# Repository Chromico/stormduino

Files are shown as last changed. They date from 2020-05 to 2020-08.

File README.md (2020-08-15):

# Stormduino Rev 2.2
An open source arduino uno clone designed in KiCad in collaboration with tecknologg and cyberstorm.mu .The board uses the CH340C as the USB to serial converter and an Atmega328p (DIP) as the microcontroller. The board design and schematic is open source so do whatever you wish with it :)

My website: https://tecknologg.website

Blog post: https://tecknologg.website/2020/02/02/stormduino-the-arduino-compatible-board-made-in-kicad/

# Front 

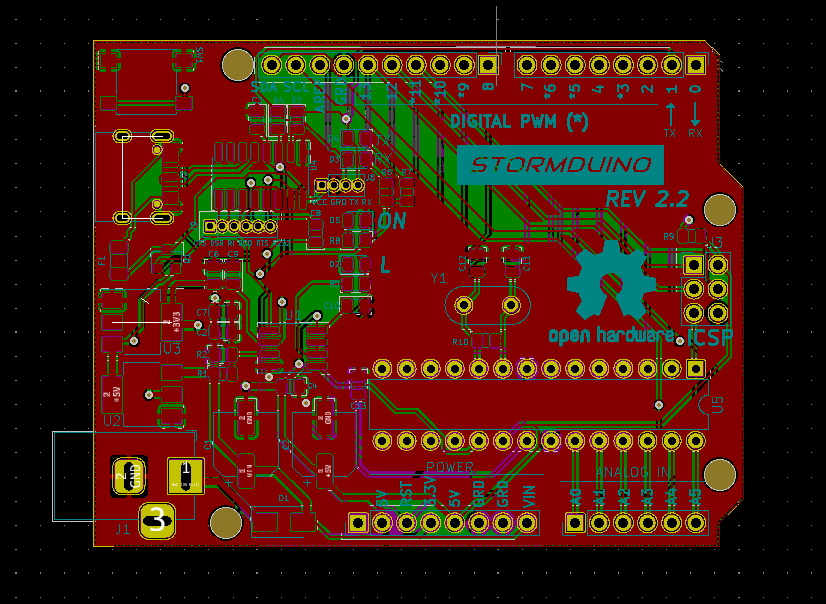
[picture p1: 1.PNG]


# Back

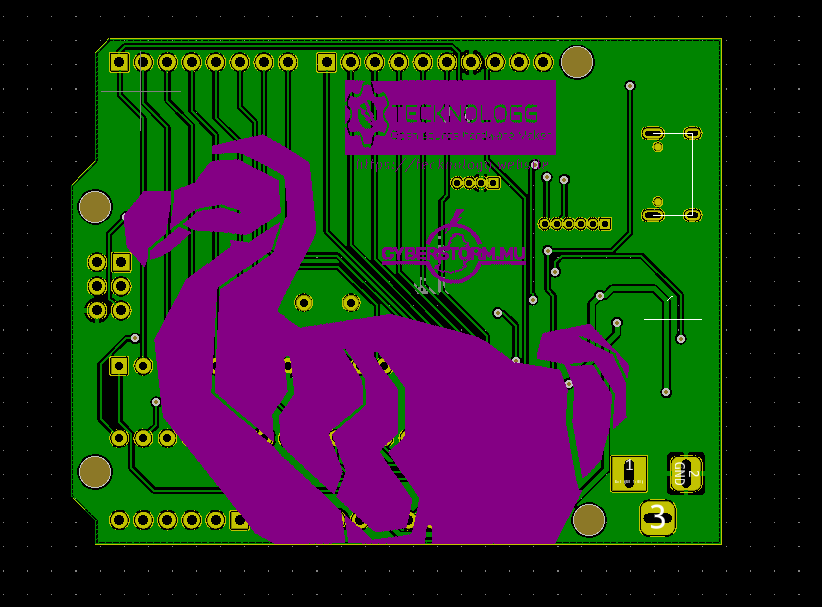
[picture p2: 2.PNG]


# Assembled board

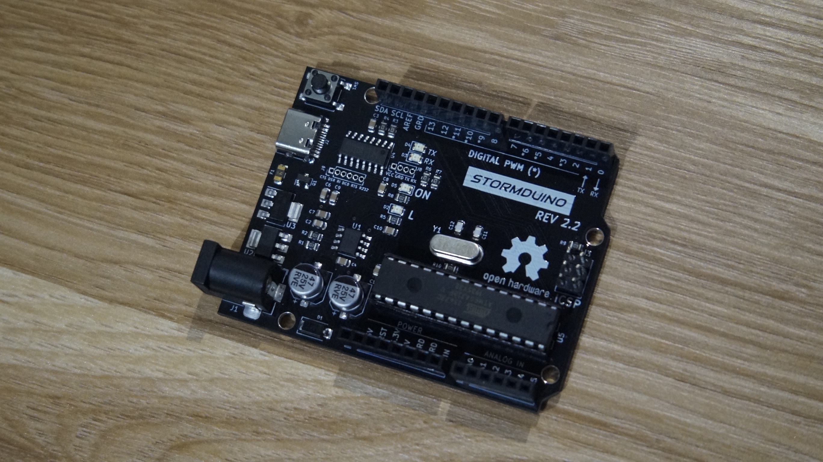
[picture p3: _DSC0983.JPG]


# Features

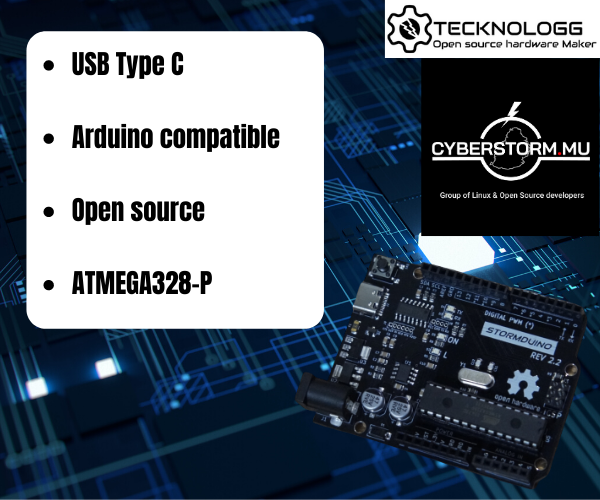
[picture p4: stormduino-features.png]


# Documentation
You can get the official documentation for stormduino here: https://github.com/Chromico/stormduino/blob/master/documentation.pdf

# Certification
As from 2020 Stormduino has the open source hardware certfication to show you that Stormduino is truly open source hardware.

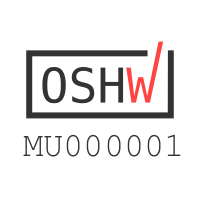
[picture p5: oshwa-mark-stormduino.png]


# Contact

Need to contact me ? Just send me an email at nathan@tecknologg.website or tecknologg@gmail.com

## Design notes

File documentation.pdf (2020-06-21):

# Stormduino Documentation

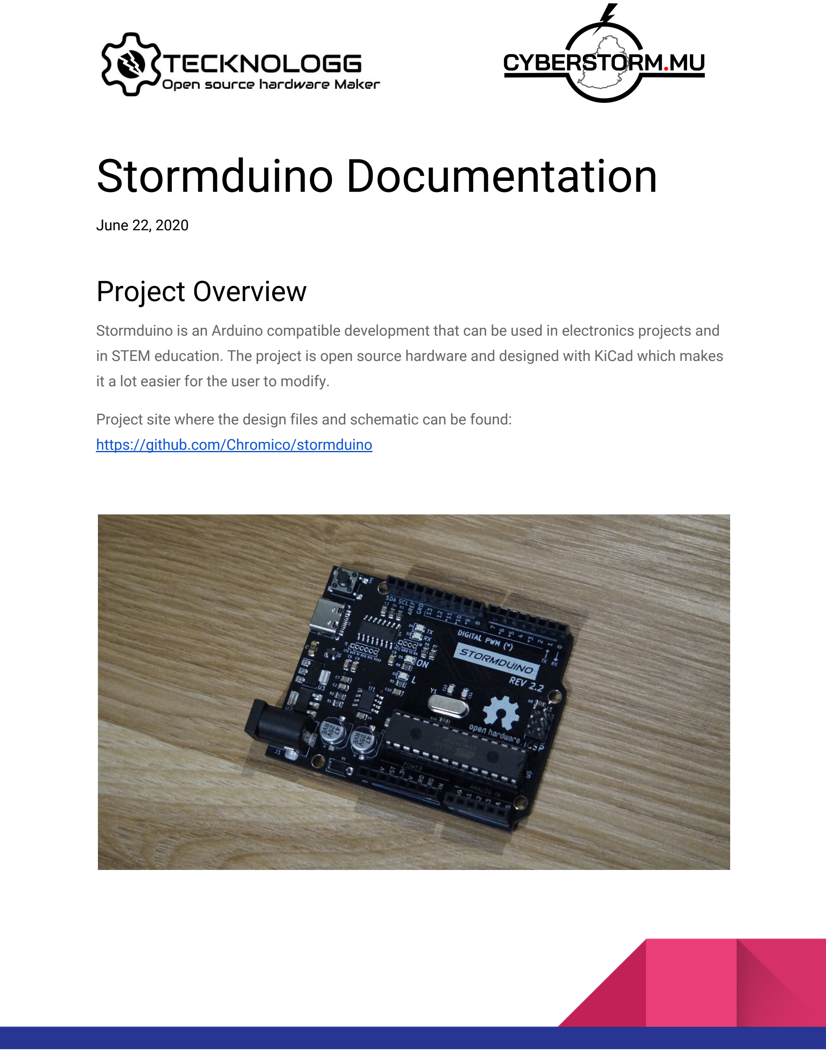
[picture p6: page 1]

June 22, 2020

# Project Overview

Stormduino is an Arduino compatible development that can be used in electronics projects and in STEM education. The project is open source hardware and designed with KiCad which makes it a lot easier for the user to modify.

Project site where the design files and schematic can be found: https://github.com/Chromico/stormduino

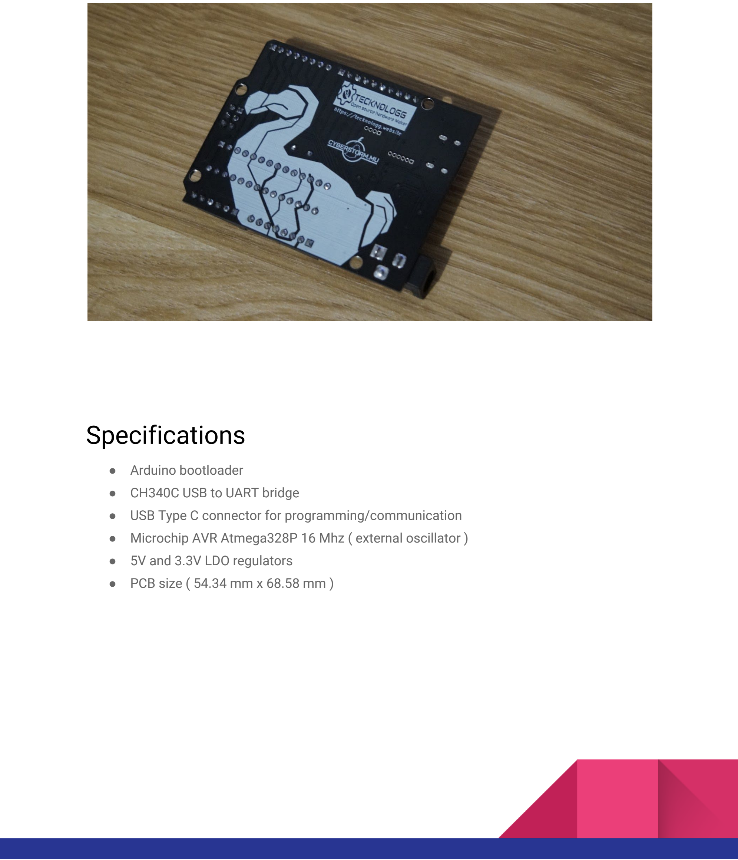
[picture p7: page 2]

# Specifications

- Arduino bootloader
- CH340C USB to UART bridge
- USB Type C connector for programming/communication
- Microchip AVR Atmega328P 16 Mhz ( external oscillator )
- 5V and 3.3V LDO regulators
- PCB size ( 54.34 mm x 68.58 mm )

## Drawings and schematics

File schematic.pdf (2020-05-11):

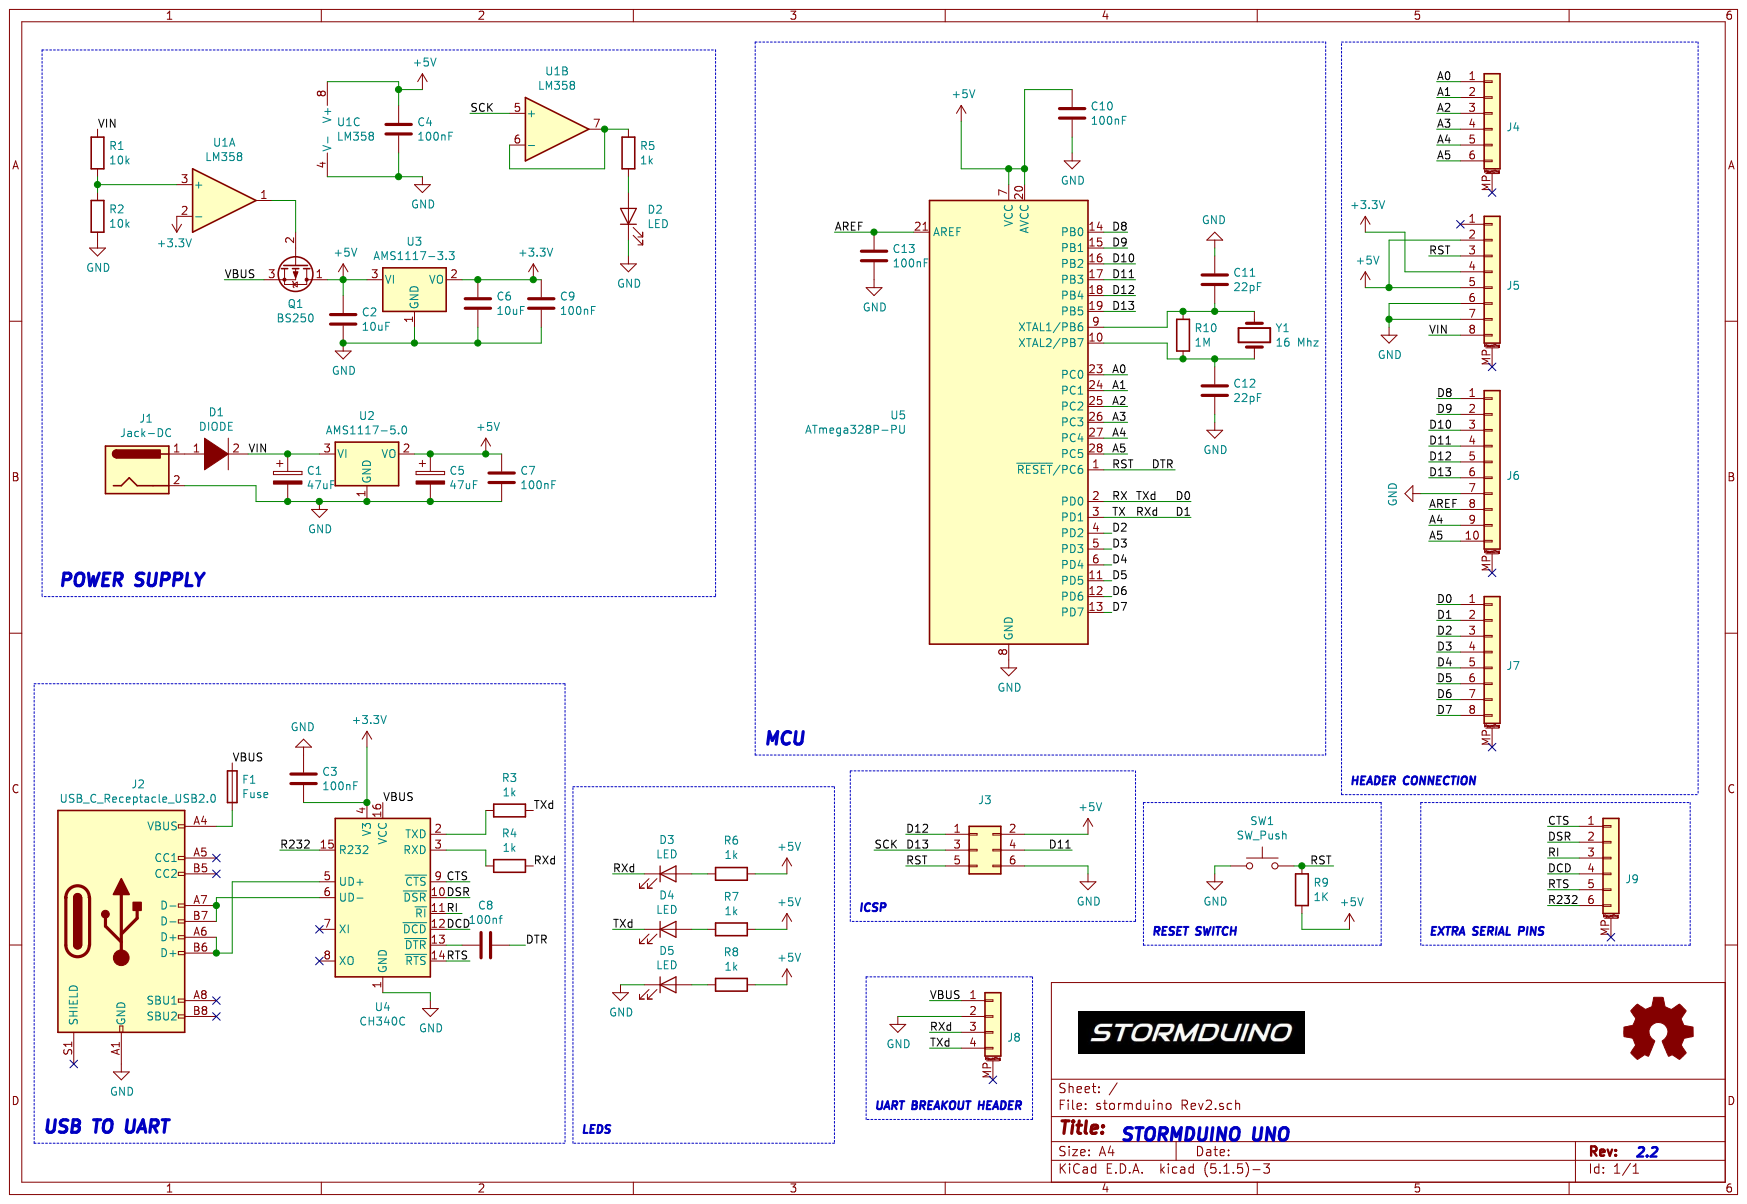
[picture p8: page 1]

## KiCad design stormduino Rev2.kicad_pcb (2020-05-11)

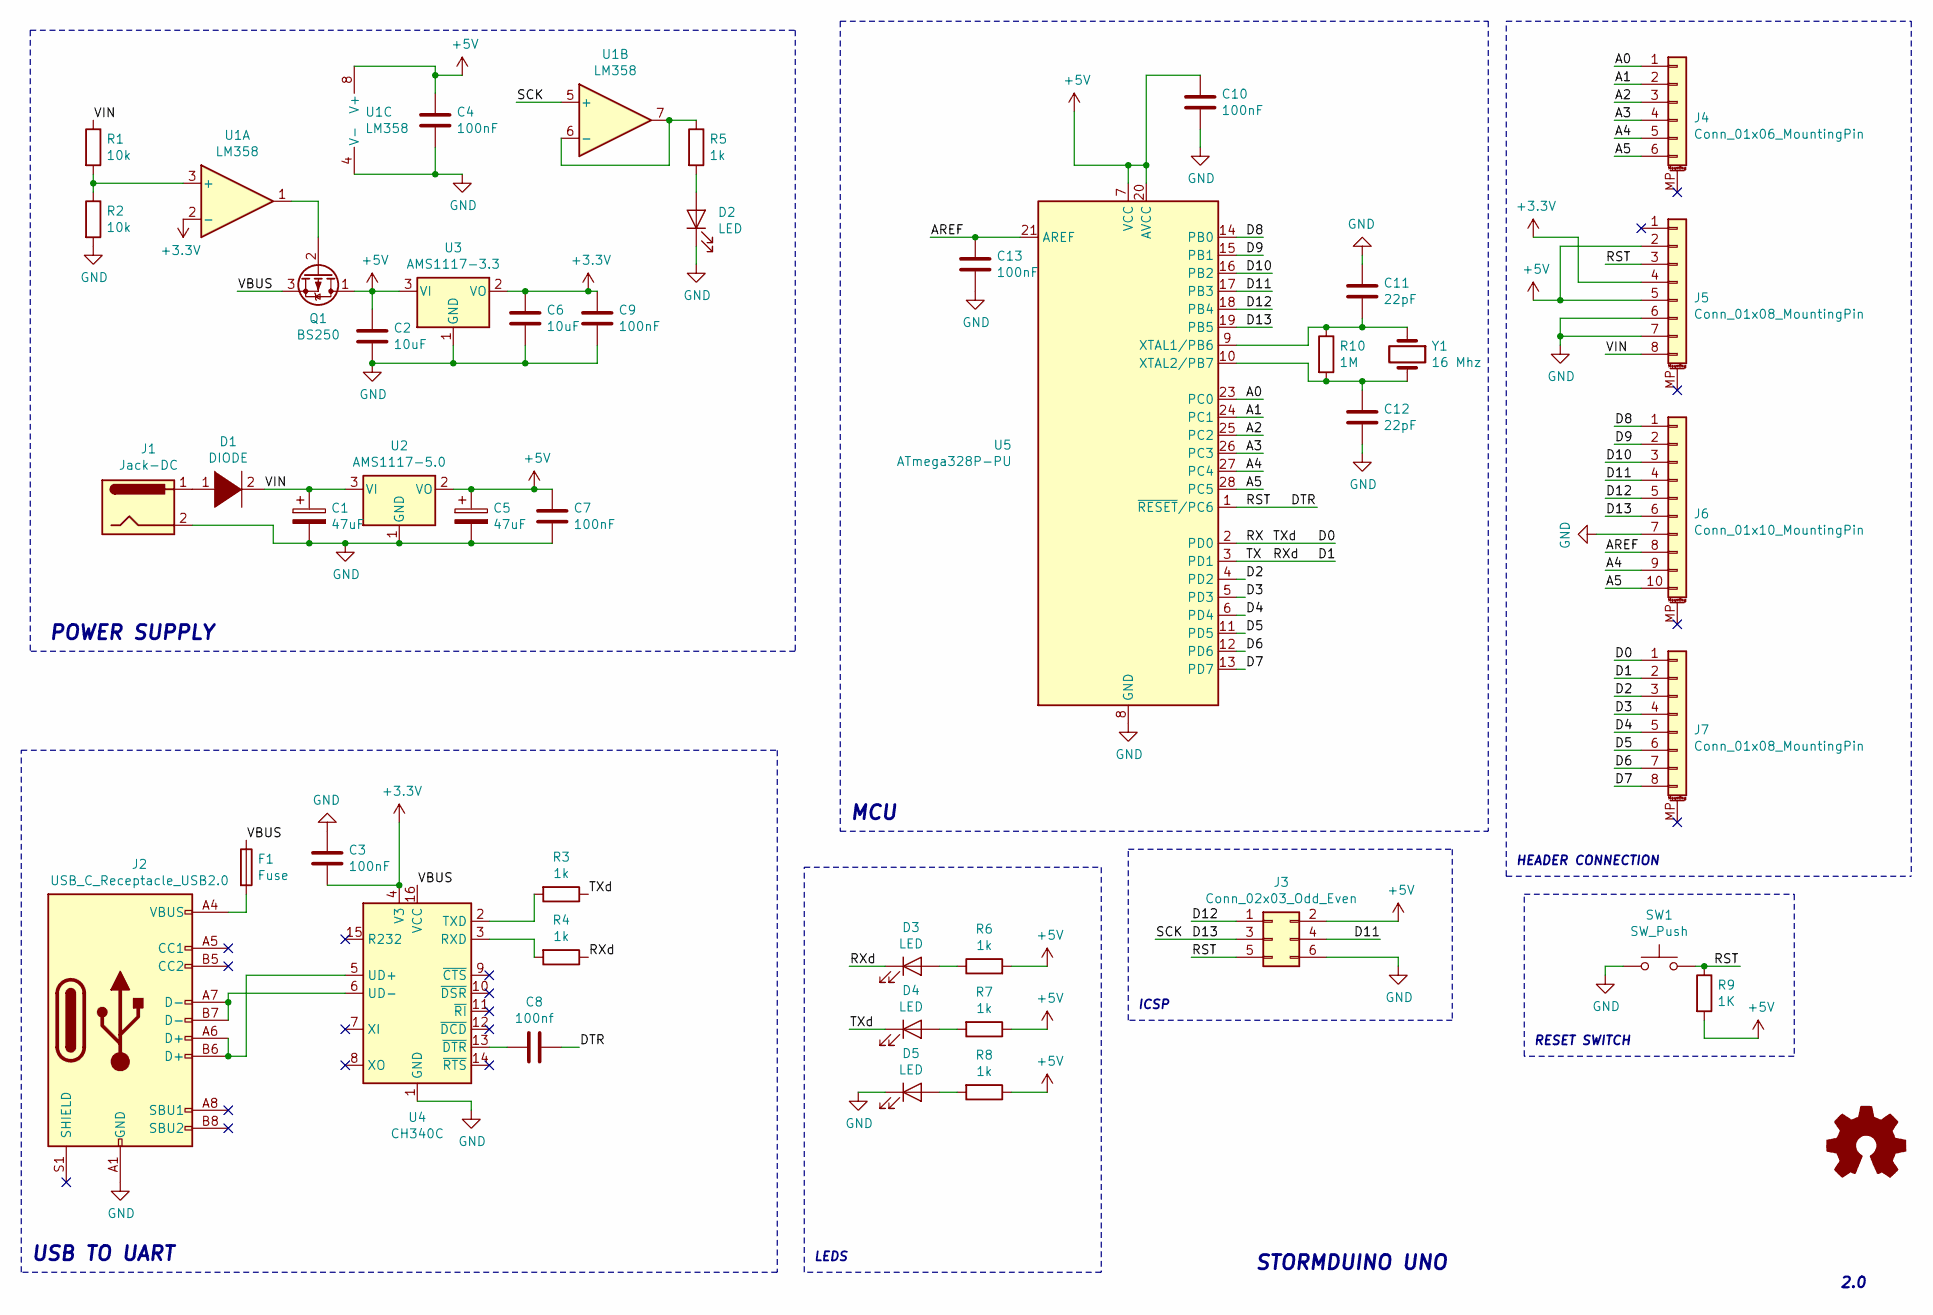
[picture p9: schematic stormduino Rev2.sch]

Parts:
C1, C5: 47uF
C2, C6: 10uF
C3, C4, C7, C9, C10, C13: 100nF
C8: 100nf
C11, C12: 22pF
D1: DIODE
D2, D3, D4, D5: LED
F1: Fuse
J1: Jack-DC
J2: USB_C_Receptacle_USB2.0
J3: Conn_02x03_Odd_Even
J4: Conn_01x06_MountingPin
J5, J7: Conn_01x08_MountingPin
J6: Conn_01x10_MountingPin
Q1: BS250; TO-92_Inline
R1, R2: 10k
R3, R4, R5, R6, R7, R8: 1k
R9: 1K
R10: 1M
SW1: SW_Push
U1: LM358
U2: AMS1117-5.0; SOT-223-3_TabPin2
U3: AMS1117-3.3; SOT-223-3_TabPin2
U4: CH340C; SOIC-16_3.9x9.9mm_P1.27mm
U5: ATmega328P-PU; DIP-28_W7.62mm
Y1: 16 Mhz

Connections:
+3V3: C3.2, C6.1, C9.1, J5.4, U1.2 (-), U3.2 (VO), U4.4 (V3)
/A0: J4.1, U5.23 (PC0)
/A1: J4.2, U5.24 (PC1)
/A2: J4.3, U5.25 (PC2)
/A3: J4.4, U5.26 (PC3)
/A4: J4.5, J6.9, U5.27 (PC4)
/A5: J4.6, J6.10, U5.28 (PC5)
/AREF: C13.1, J6.8, U5.21 (AREF)
/CTS: U4.9 (~CTS); also elsewhere on the board
/D0: D4.1 (K), J7.1, R3.1, U5.2 (PD0); also elsewhere on the board
/D1: D3.1 (K), J7.2, R4.1, U5.3 (PD1); also elsewhere on the board
/D2: J7.3, U5.4 (PD2)
/D3: J7.4, U5.5 (PD3)
/D4: J7.5, U5.6 (PD4)
/D5: J7.6, U5.11 (PD5)
/D6: J7.7, U5.12 (PD6)
/D7: J7.8, U5.13 (PD7)
/D8: J6.1, U5.14 (PB0)
/D9: J6.2, U5.15 (PB1)
/D10: J6.3, U5.16 (PB2)
/D11: J3.4, J6.4, U5.17 (PB3)
/D12: J3.1, J6.5, U5.18 (PB4)
/D13: J3.3, J6.6, U1.5 (+), U5.19 (PB5)
/DCD: U4.12 (~DCD); also elsewhere on the board
/DSR: U4.10 (~DSR); also elsewhere on the board
/DTR: C8.1, J3.5, J5.3, R9.1, SW1.2, U5.1 (~RESET~/PC6)
/R232: U4.15 (R232); also elsewhere on the board
/RI: U4.11 (~RI); also elsewhere on the board
/RTS: U4.14 (~RTS); also elsewhere on the board
/VBUS: F1.1, Q1.3 (S), U4.16 (VCC); also elsewhere on the board
/VIN: C1.1, D1.2 (A), J5.8, R1.1, U2.3 (VI)
GND: C1.2, C2.2, C3.1, C4.2, C5.2, C6.2, C7.2, C9.2, C10.2, C11.1, C12.2, C13.2, D2.1 (K), D5.1 (K), J1.2, J2.A1 (GND), J2.A12 (GND), J2.B1 (GND), J2.B12 (GND), J3.6, J5.6, J5.7, J6.7, R2.2, SW1.1, U1.4 (V-), U2.1 (GND), U3.1 (GND), U4.1 (GND), U5.8 (GND), U5.22 (GND); also elsewhere on the board
unnamed: C8.2, U4.13 (~DTR)
unnamed: C11.2, R10.1, U5.9 (XTAL1/PB6), Y1.1
unnamed: C12.1, R10.2, U5.10 (XTAL2/PB7), Y1.2
unnamed: D1.1 (K), J1.1
unnamed: D2.2 (A), R5.2
unnamed: D3.2 (A), R6.1
unnamed: D4.2 (A), R7.2
unnamed: D5.2 (A), R8.2
unnamed: F1.2, J2.A4 (VBUS), J2.A9 (VBUS), J2.B4 (VBUS), J2.B9 (VBUS)
unnamed: J2.A6 (D+), J2.B6 (D+), U4.5 (UD+)
unnamed: J2.A7 (D-), J2.B7 (D-), U4.6 (UD-)
unnamed: R1.2, R2.1, U1.3 (+)
unnamed: R3.2, U4.2 (TXD)
unnamed: R4.2, U4.3 (RXD)
unnamed: R5.1, U1.6 (-), U1.7

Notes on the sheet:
POWER SUPPLY
USB TO UART
MCU
STORMDUINO UNO
2.0
ICSP
HEADER CONNECTION
LEDS
RESET SWITCH

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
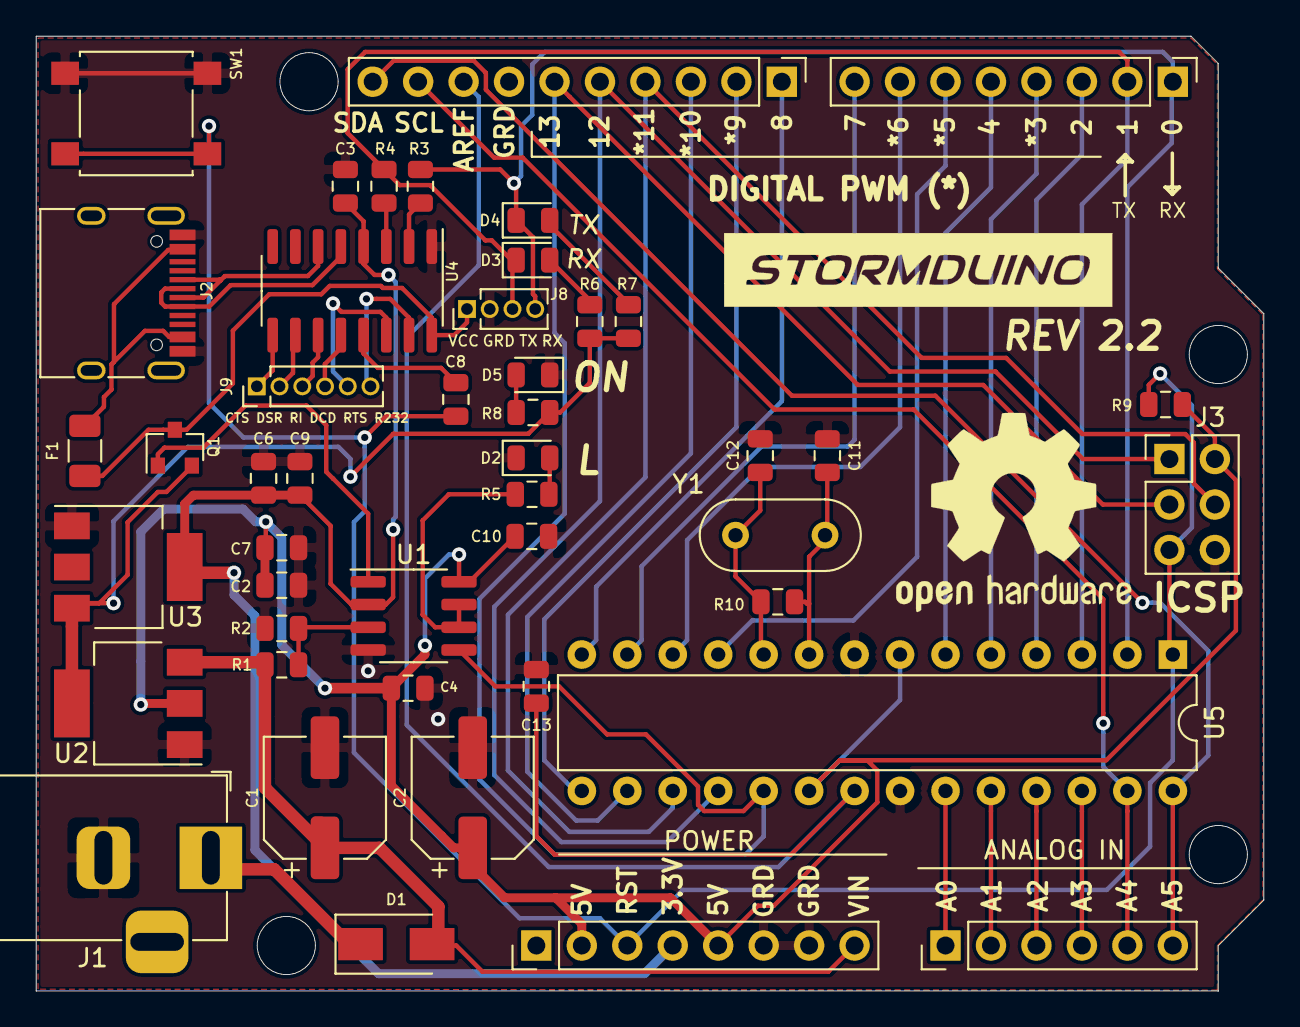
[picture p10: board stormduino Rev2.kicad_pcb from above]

Board: 2 copper layers, 68.6 x 53.3 mm, 46 parts (0 on the bottom side), 49 nets.

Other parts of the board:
C2#2: 10uF; C_0805_2012Metric
J8: Conn_01x04_MountingPin; PinHeader_1x04_P1.27mm_Vertical
J9: Conn_01x06_MountingPin; PinHeader_1x06_P1.27mm_Vertical

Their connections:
/CTS: J9.1; also elsewhere on the board
/D0: J8.4; also elsewhere on the board
/D1: J8.3; also elsewhere on the board
/DCD: J9.4; also elsewhere on the board
/DSR: J9.2; also elsewhere on the board
/R232: J9.6; also elsewhere on the board
/RI: J9.3; also elsewhere on the board
/RTS: J9.5; also elsewhere on the board
/VBUS: J8.1; also elsewhere on the board
GND: C2#2.2, J8.2; also elsewhere on the board
